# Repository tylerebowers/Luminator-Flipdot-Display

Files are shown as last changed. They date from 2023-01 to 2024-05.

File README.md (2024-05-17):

# Luminator Flipdot Display
 These signs were used in busses to display route information and service status, now they are replaced with led signs (how boring). Flipdots are physical disks "dots" that flip based on an electomagnetic impulse. The only original parts in this project are the flipdot boards themselves (and cables). Though the list is oversimplified, this is what I had to do:   
  * Reverse engineer pinnouts and board workings.
  * Design a PCB driver to drive the display (in Kicad).
  * Software to run on the driver board (C++ on esp32).
  * Software to control the driver board (Python on RPI).
  * Fabricate an enclosure to mount the boards and controllers.  

This project is on hold until I have time to complete the software and make some finishing touches to the housing.

## Pictures (videos in media folder too!)

### Finished (almost) display
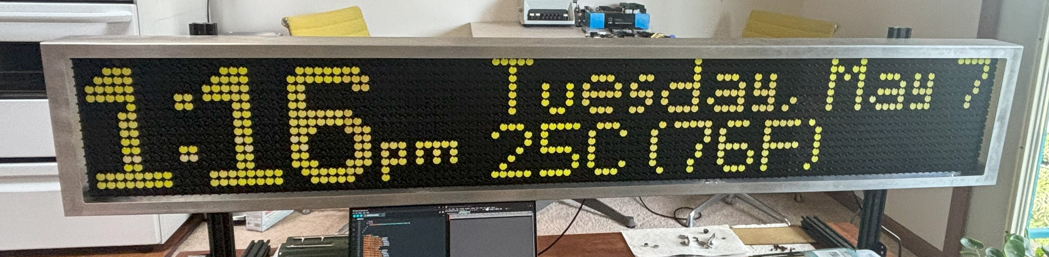
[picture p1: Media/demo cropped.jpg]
Picture of display


### Board
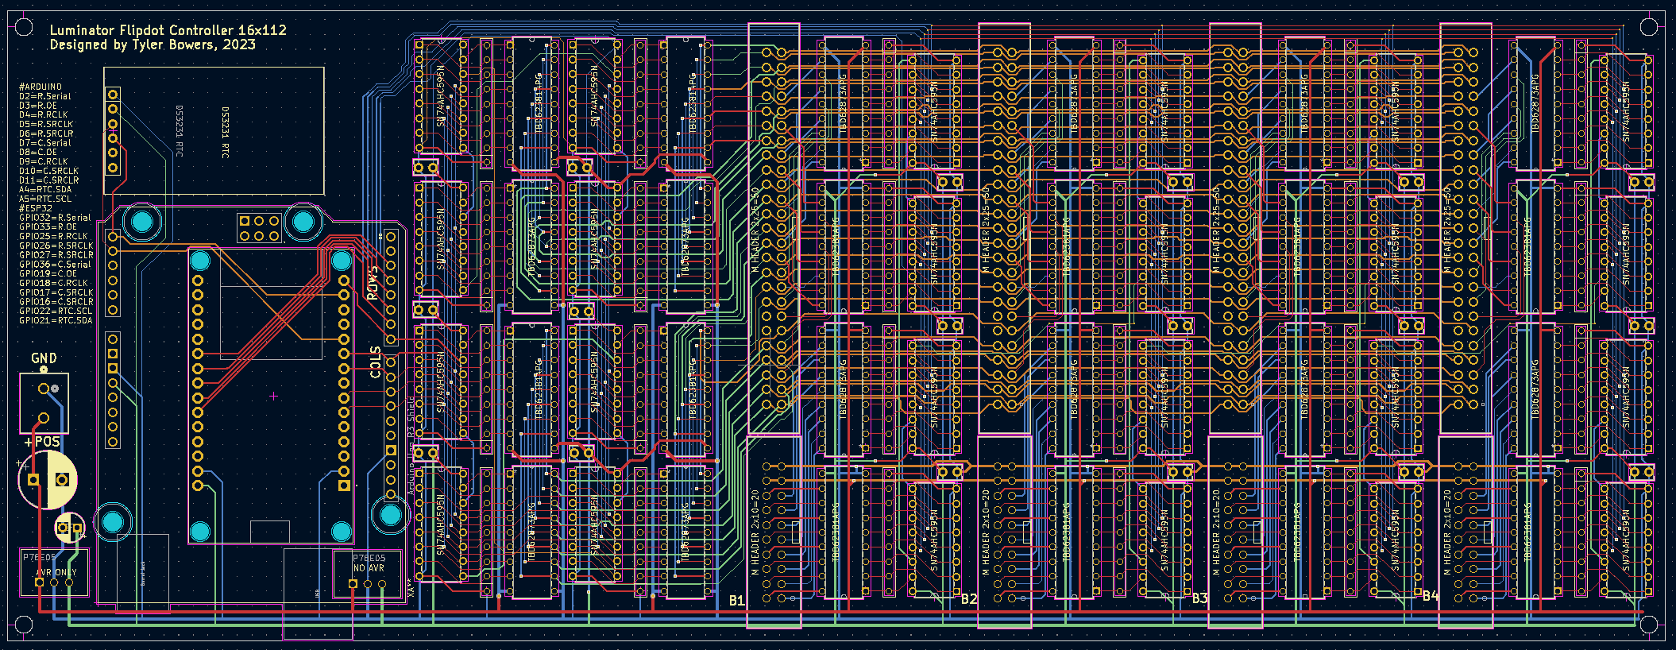
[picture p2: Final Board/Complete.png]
Picture of board


### Populated Board
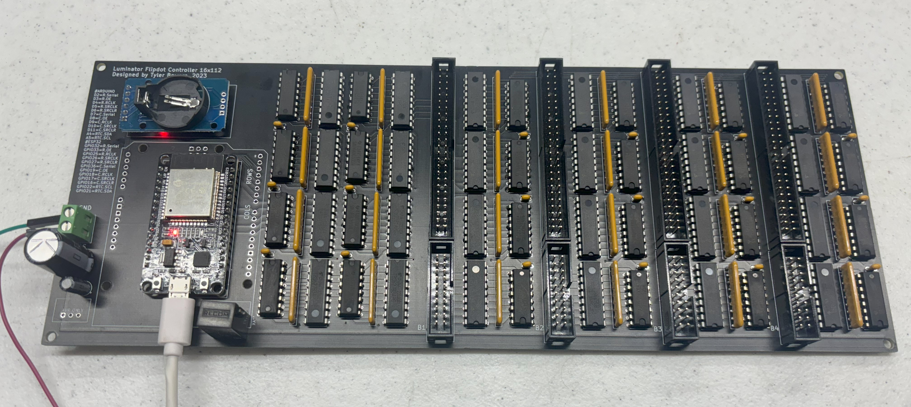
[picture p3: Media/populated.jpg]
Picture of all dots


### Pinnouts
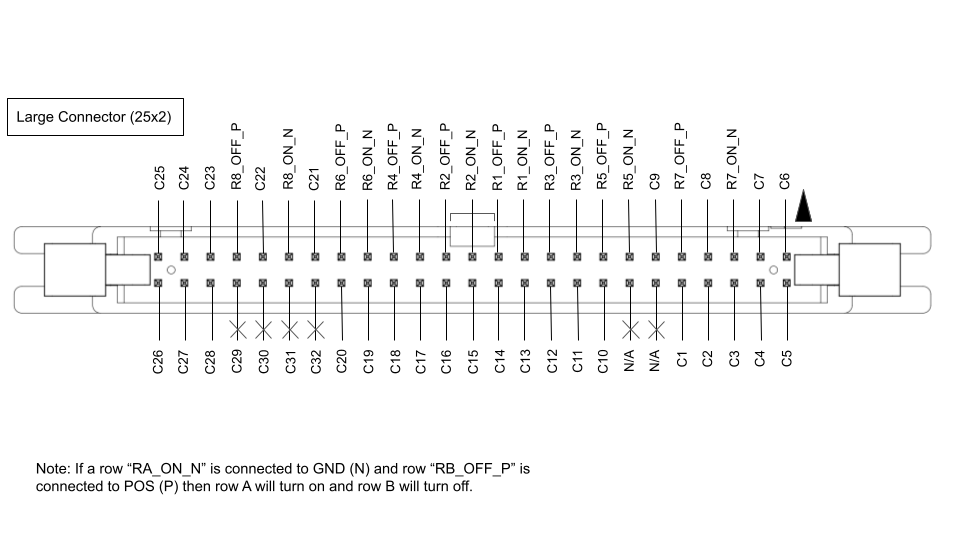
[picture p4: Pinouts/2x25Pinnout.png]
Pinnout 1

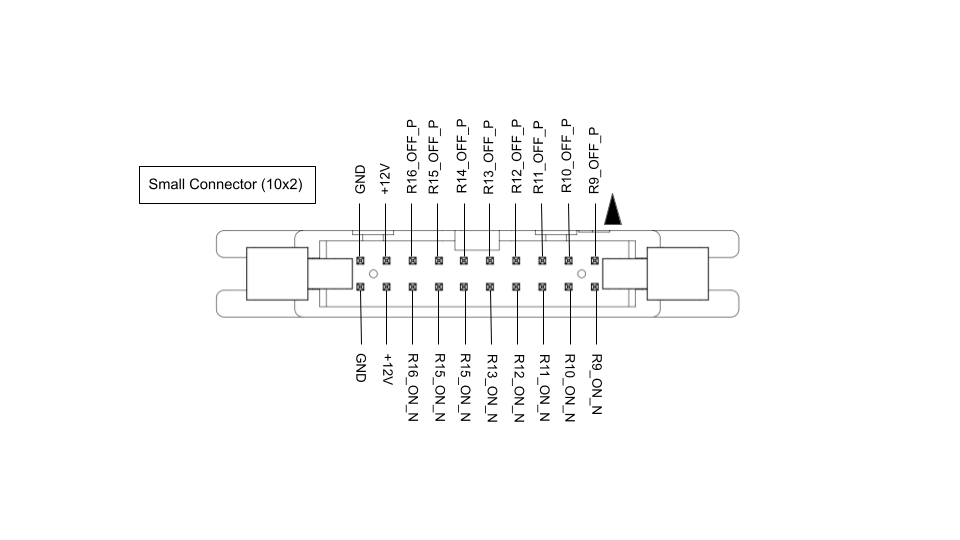
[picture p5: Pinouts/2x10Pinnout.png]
Pinnout 2


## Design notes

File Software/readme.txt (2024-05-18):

The esp32 is on the driver board and it controls the registers and outputs it was originally intended to do the job that the pi now does.
The rpi (zero 2 W) connects over serial (micro-b to micro-b) and runs the software that controls the esp32/driver board. The rpi is better for storing graphics libraries, running webservers, and python is easier to work with so no reflashing everytime a change is made.

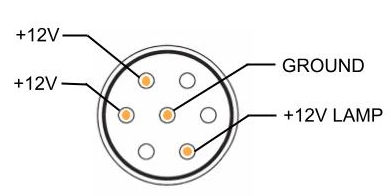
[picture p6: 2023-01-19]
Pinouts/original power connector.jpg

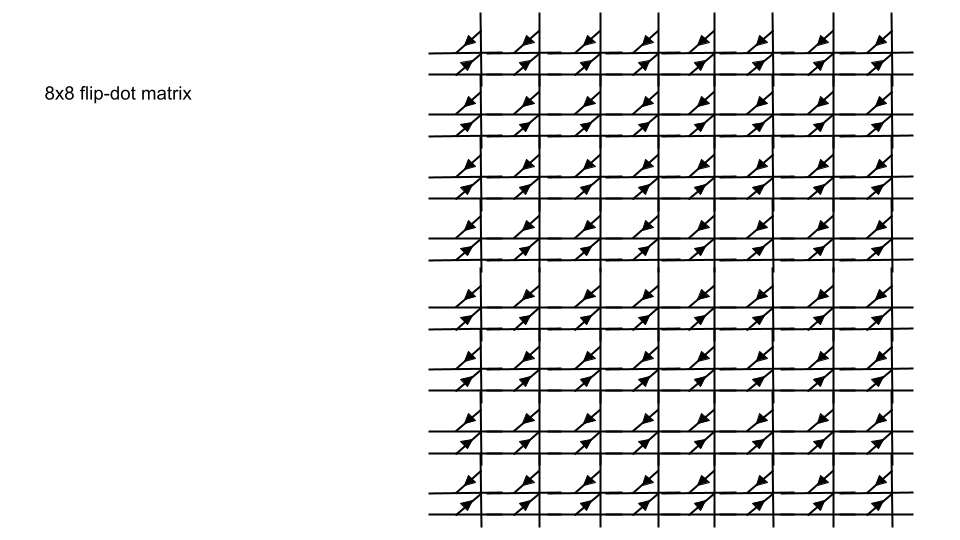
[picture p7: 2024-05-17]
Pinouts/Grid.png

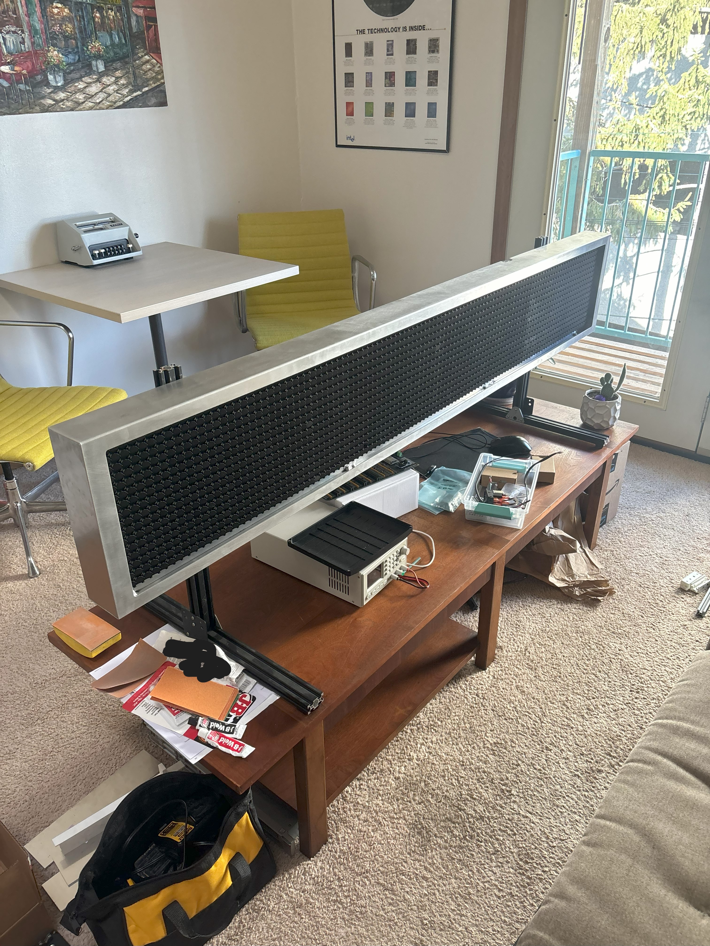
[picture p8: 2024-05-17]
Media/on table.jpg

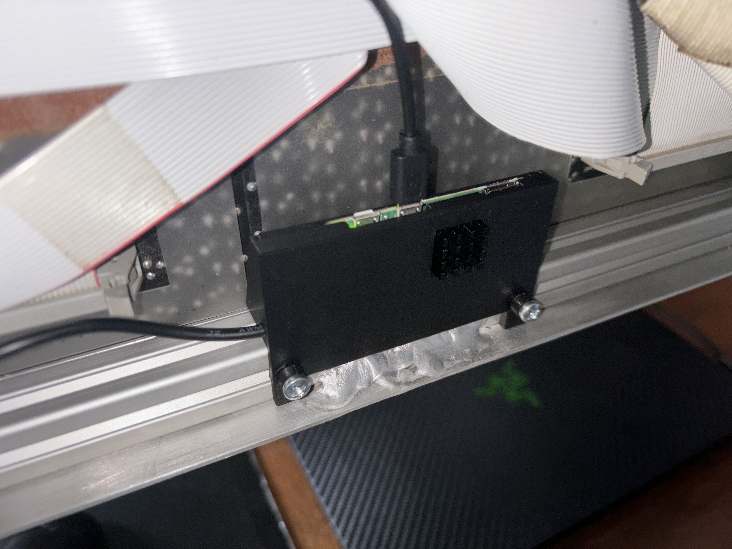
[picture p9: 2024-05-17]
Media/rpi.JPG

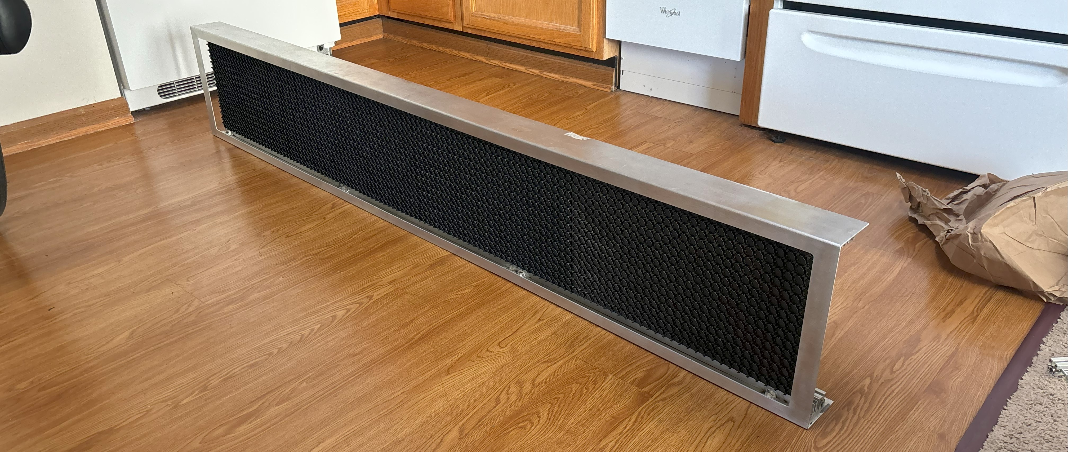
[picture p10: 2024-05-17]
Media/boards in frame.jpg

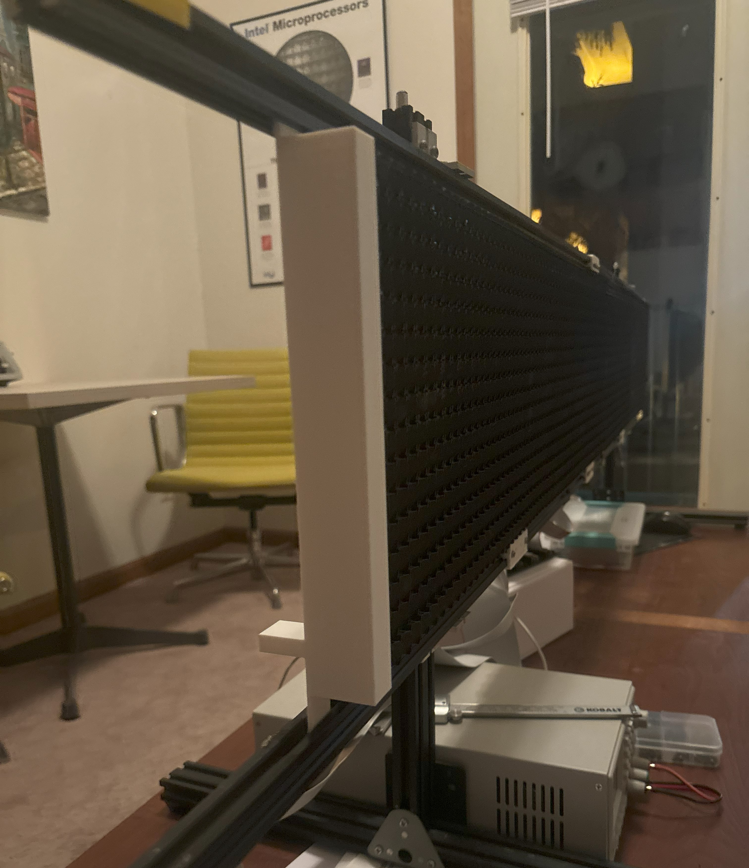
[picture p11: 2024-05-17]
Media/panel profile.jpg

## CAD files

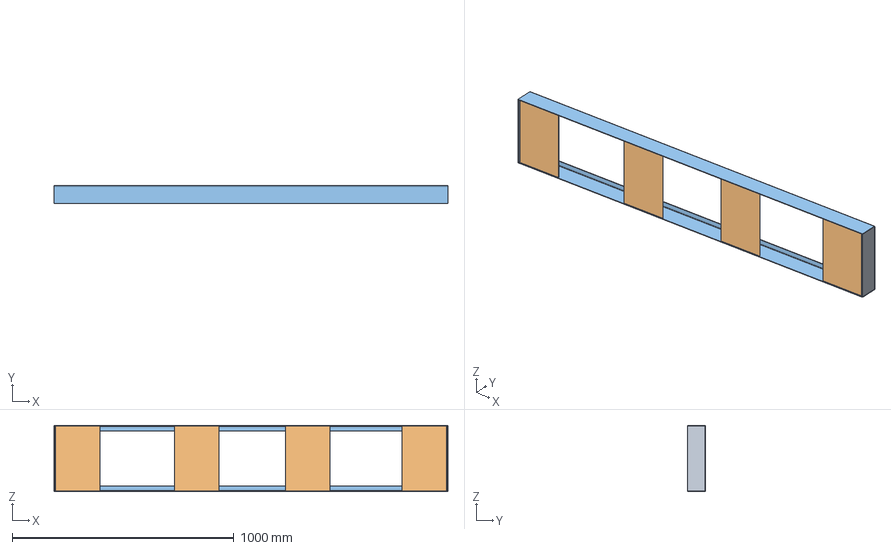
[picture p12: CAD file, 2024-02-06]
Cad/aluminum/Cover FULL.step
1775.8 x 82.3 x 297.8 mm

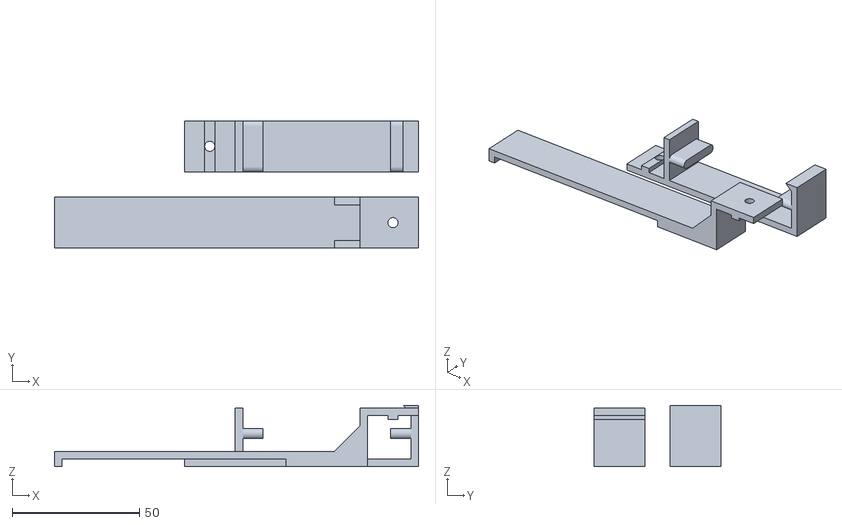
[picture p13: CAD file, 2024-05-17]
Cad/3d print/cable management.stl
143.0 x 50.0 x 24.0

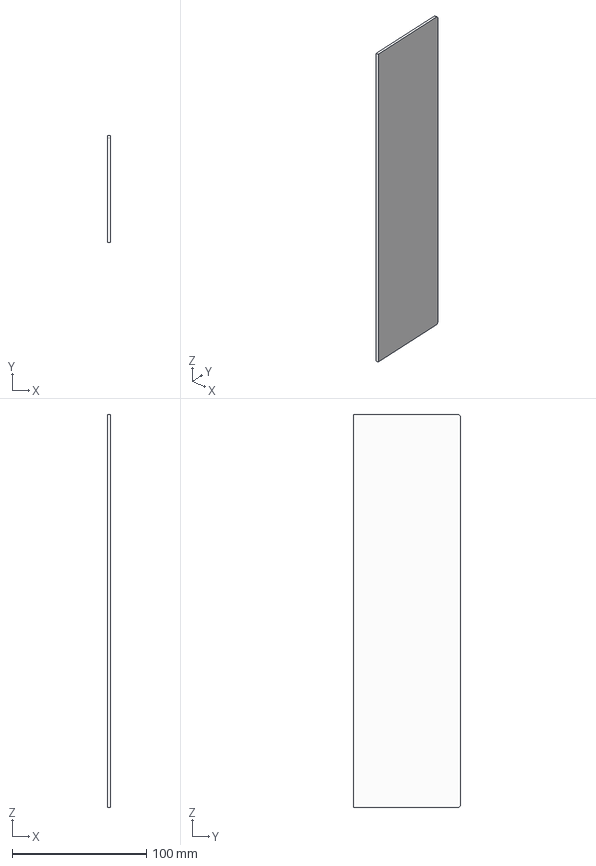
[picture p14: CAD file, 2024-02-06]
Cad/aluminum/2x Side Board.step
2.29 x 79.8 x 292.8 mm

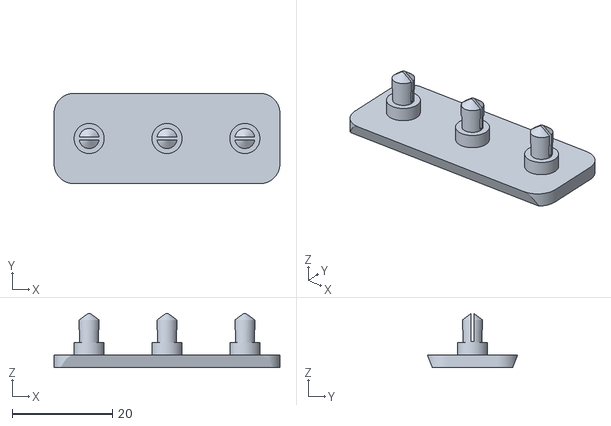
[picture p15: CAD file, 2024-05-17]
Cad/3d print/insulation clip.stl
45.0 x 18.0 x 10.8

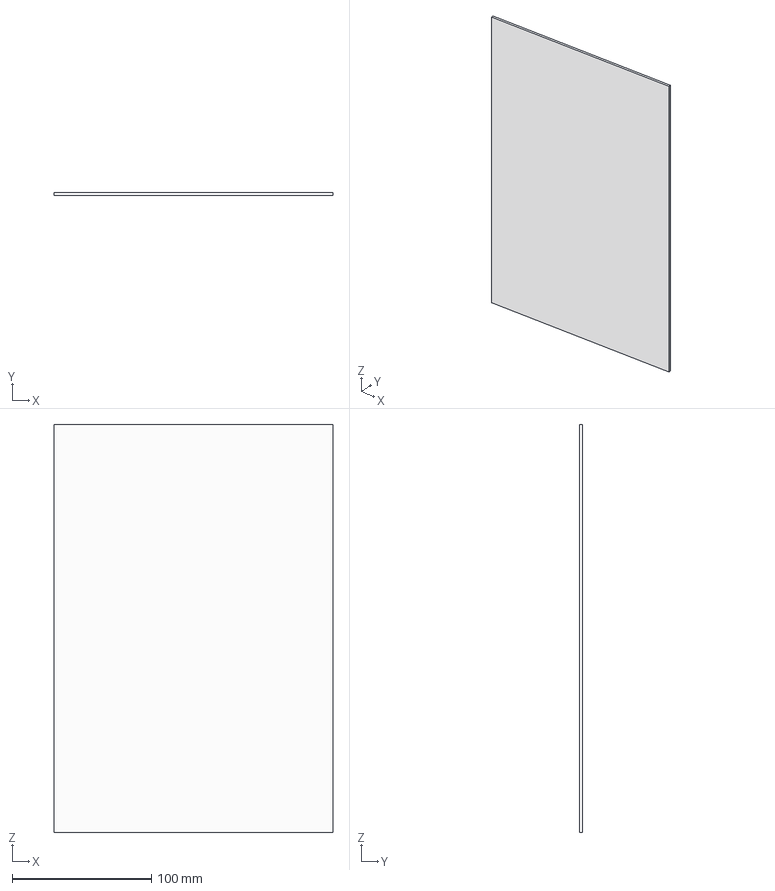
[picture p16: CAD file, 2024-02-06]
Cad/aluminum/4x BackerBoard.step
200.0 x 2.29 x 292.8 mm

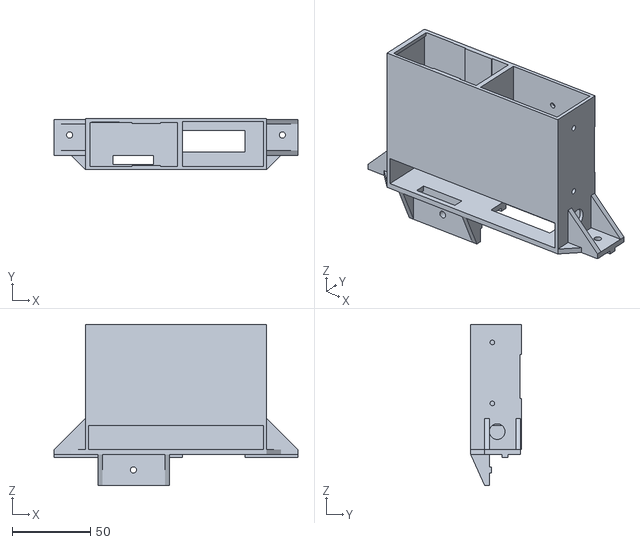
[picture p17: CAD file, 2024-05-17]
Cad/3d print/psu.stl
156.0 x 32.5 x 103.0

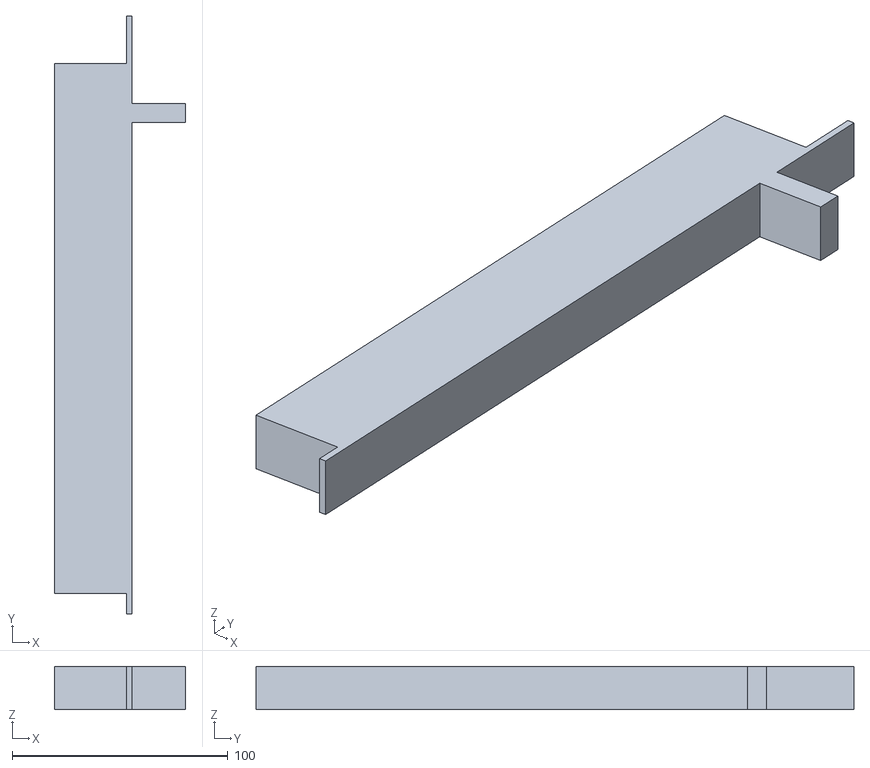
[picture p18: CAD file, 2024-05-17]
Cad/3d print/flipdot bard cross section.stl
61.0 x 277.5 x 20.0

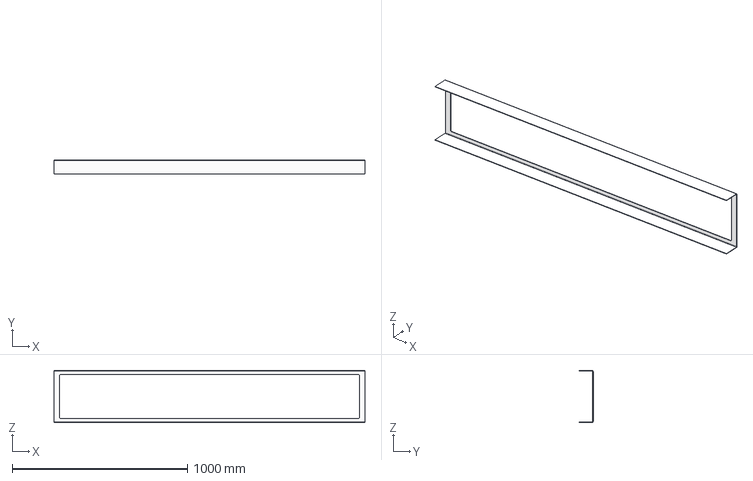
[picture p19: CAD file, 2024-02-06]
Cad/aluminum/Cover.step
1775.8 x 82.3 x 297.8 mm

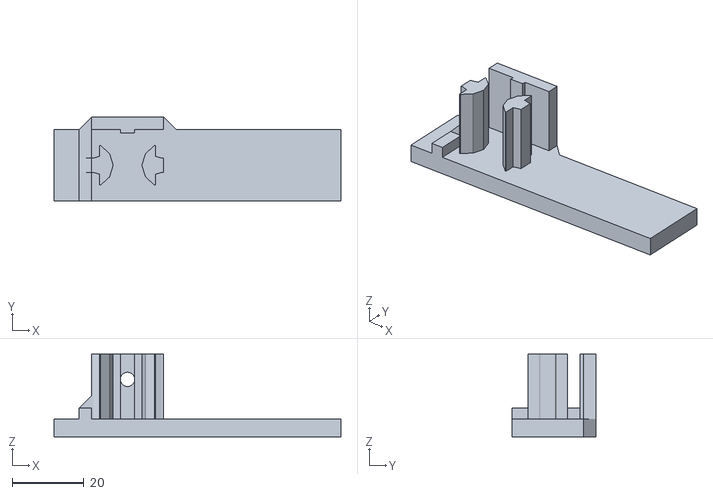
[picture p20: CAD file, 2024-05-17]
Cad/3d print/corner.stl
80.0 x 23.5 x 23.0

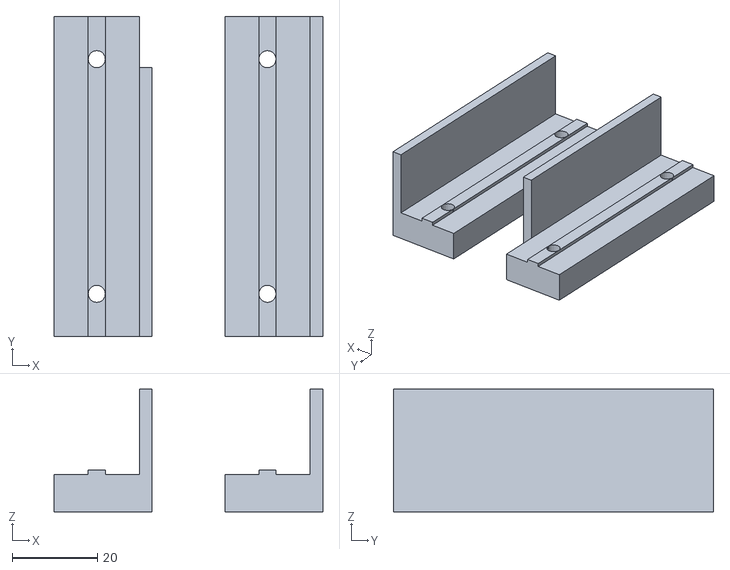
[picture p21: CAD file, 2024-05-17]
Cad/3d print/mounting spacers.stl
63.0 x 75.0 x 28.8

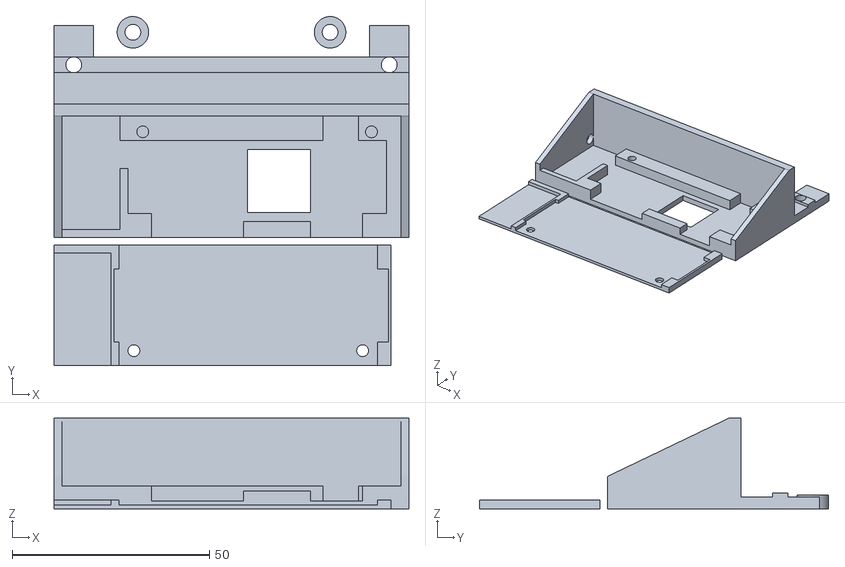
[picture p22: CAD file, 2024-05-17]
Cad/3d print/rpi case.stl
90.0 x 88.5 x 23.0

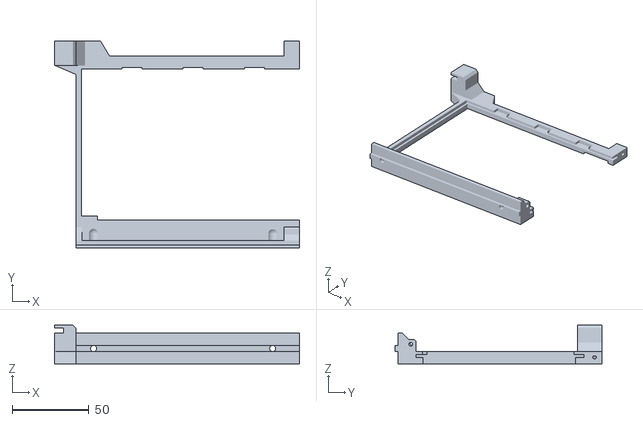
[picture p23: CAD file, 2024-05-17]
Cad/3d print/driver right.stl
160.0 x 135.5 x 25.2

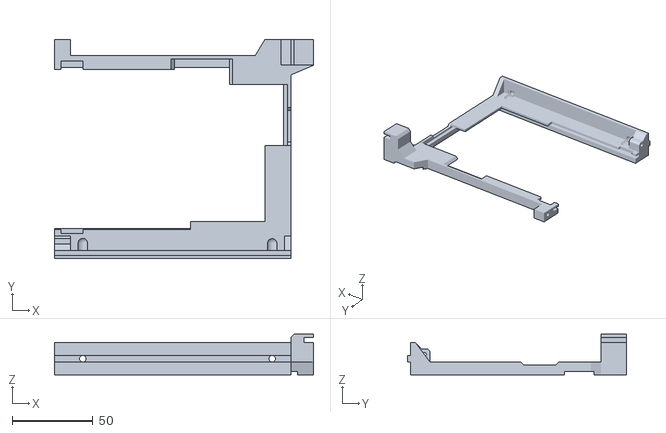
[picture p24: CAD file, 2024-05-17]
Cad/3d print/driver left.stl
160.0 x 135.5 x 25.2

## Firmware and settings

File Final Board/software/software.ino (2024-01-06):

#include <string.h>
#include <WiFi.h>
#include <RTClib.h>
//#include <time.h> 
#include <Wire.h>
#include <LinkedList.h>
//#include "libraries.h"

#define FLASHTIME 200   //in microseconds
#define TIMEZONE "EST5EDT,M3.2.0,M11.1.0"
#define NTP_SERVER "pool.ntp.org"
#define WIFI_SSID ""
#define WIFI_PASSWORD ""

RTC_DS3231 RTC;
DateTime RTCnow;
uint8_t shownMinute = 61;
time_t now;

struct Display{
  uint8_t numRows = 16;
  uint8_t numCols = 112;    // numCols = numBoards * numColsPerBoard
  uint8_t numBoards = 4;
  uint8_t numColsPerBoard = 28;
  uint16_t shown[112];    // datatype is uint16_t because numRows = 16 

  struct Rows{
    uint8_t SER = 32;
    uint8_t OE = 33;
    uint8_t RCLK = 25;
    uint8_t SRCLK = 26;
    uint8_t SRCLR = 27;
    void disable() {
      digitalWrite(OE, HIGH); // disable
    }
    void enable(){
      digitalWrite(OE, LOW); // enable
    }
    void clear(){
      digitalWrite(SRCLR, LOW); // clear
      digitalWrite(SRCLR, HIGH); // clear
    }
    void incrementSR(){
      digitalWrite(SRCLK, HIGH);
      digitalWrite(SRCLK, LOW);
    }
    void incrementR(){
      digitalWrite(RCLK, HIGH);
      digitalWrite(RCLK, LOW);
    }
    void setIdle(){
      digitalWrite(SER, LOW);
    }
  } rows;

  struct Columns{
    uint8_t SER = 23;
    uint8_t OE = 19;
    uint8_t RCLK = 18;
    uint8_t SRCLK = 17;
    uint8_t SRCLR = 16;
    void disable() {
      digitalWrite(OE, HIGH); // disable
    }
    void enable(){
      digitalWrite(OE, LOW); // enable
    }
    void clear(){
      digitalWrite(SRCLR, LOW); // clear
      digitalWrite(SRCLR, HIGH); // clear
    }
    void incrementSR(){
      digitalWrite(SRCLK, HIGH);
      digitalWrite(SRCLK, LOW);
    }
    void incrementR(){
      digitalWrite(RCLK, HIGH);
      digitalWrite(RCLK, LOW);
    }
    void setIdle(){
      digitalWrite(SER, LOW);
    }
  } cols;

  void toggleColumn(short c, bool state){
    cols.disable();
    cols.clear();
    c = c%numColsPerBoard;
    for(int8_t i = 3; i >=0; i--){
      short c_offset = i*8;
      for(int8_t j = 7; j >= 0; j--){ // writes +POS (83) (ON)
        if((j+c_offset == c) && state){
          digitalWrite(cols.SER, HIGH);
        }
        else{
          digitalWrite(cols.SER, LOW);
        }
        cols.incrementSR();
      }
      for(int8_t j = 7; j >= 0; j--){ // writes -GND (81) (OFF)
        if((j+c_offset == c) && !state){
          digitalWrite(cols.SER, HIGH);
        }
        else{
          digitalWrite(cols.SER, LOW);
        }
        cols.incrementSR();
      }
    }
    cols.incrementR();
    cols.setIdle();
  }

  void toggleRow(short r, short c, short state){
    rows.disable();
    rows.clear();
    int8_t board = c/numColsPerBoard;
    for(int8_t b = board; b>=0; b--){
      for(int8_t i = 1; i >=0; i--){
        short r_offset = i*8;
        for(int8_t j = 7; j >= 0; j--){ // writes +POS (83) (OFF)
          if((j+r_offset == r) && !state && (b == board)){
            digitalWrite(rows.SER, HIGH);
          }
          else{
            digitalWrite(rows.SER, LOW);
          }
          rows.incrementSR();
        }
        for(int8_t j = 7; j >= 0; j--){ // writes -GND (81) (ON)
          if((j+r_offset == r) && state && (b == board)){
            digitalWrite(rows.SER, HIGH);
          }
          else{
            digitalWrite(rows.SER, LOW);
          }
          rows.incrementSR();
        }
      }
    }
    rows.incrementR();
    rows.setIdle();
  }

  void flash(short delayTime = FLASHTIME){    // turn on rows and colums for FLASHTIME microseconds 
    rows.enable();
    cols.enable();
    delayMicroseconds(delayTime);
    cols.disable();
    rows.disable();
  }

  void writeDot(uint8_t c, uint8_t r, bool state){ // one dot at a time
    toggleRow(r, c, state);
    toggleColumn(c, state);
    flash();
    shown[c] = (shown[c] & (~(1 << r))) | (state << r);
  }
/*
  void writeCol(uint16_t col, uint8_t x, uint8_t yS, uint8_t yF){ 
    for(uint8_t r = yS; r < min(numRows, yF); r++){ // do each row 
      bool newDot = ((col >> r-yS) & 1);
      if(newDot != ((shown[x] >> r) & 1)){
        writeDot(x, r, newDot);
      }
    }
  }
*/
  void write(uint16_t * array, uint8_t xLim, uint8_t x = 0, uint8_t y = 0, uint8_t yLim = 32){ 
    for(uint8_t c = x; c < numCols && c-x < xLim; c++){ // For each column
      for(uint8_t r = y; r < numRows && r-y < yLim; r++){ // do each row 
        bool newDot = ((array[c-x] >> r-y) & 1);
        if(newDot != ((shown[c] >> r) & 1)){
          writeDot(c, r, newDot);
        }
      }
    }
  }

  void allOff(bool full = true, uint16_t delayTime = 5){
    for(uint8_t j = 0; j<numRows; j++){
      for(uint8_t i = 0; i<numCols; i++){
        if(((shown[j] >> i) & 1) || full){
          writeDot(i,j,0);
          delay(delayTime);
        }
      } 
    }
    for(uint8_t i = 0; i<numCols; i++){
      shown[i] = 0;
    }
  }

  void allOn(bool full = true, uint16_t delayTime = 5){
    for(uint8_t j = 0; j<numRows; j++){
      for(uint8_t i = 0; i<numCols; i++){
        if(((shown[j] >> i) & 0) || full){
          writeDot(i,j,1);
          delay(delayTime);
        }
      } 
    }
    for(uint8_t i = 0; i<numCols; i++){
      shown[i] = 65535;
    }
  }

  void allInvert(uint16_t delayTime = 5){
    for(uint8_t j = 0; j<numRows; j++){
      for(uint8_t i = 0; i<numCols; i++){
        if(((shown[j] >> i) & 1)){
          writeDot(i,j,0);
        } else {
          writeDot(i,j,1);
        }
        delay(delayTime);
      } 
    }
    for(uint8_t i = 0; i<numCols; i++){
      shown[i] = 65535 - shown[i];
    }
  }

} display;


struct UI{


  uint16_t space[1] = {0};

  uint16_t ascii57[95][5] = {	//7r x 5c
    {0,0,0,0,0},      //" "
    {0,0,95,0,0},		  //!
    {0,3,0,3,0},		  //"
    {20,62,20,62,20},	//#
    {70,73,127,73,49},//$
    {6,102,28,51,48},	//%
    {54,73,81,38,88},	//&
    {0,0,3,0,0},		  //'
    {0,62,65,0,0},		//(
    {0,0,65,62,0},		//)
    {0,5,2,5,0},		  //*
    {0,8,28,8,0},	  	//+
    {0,64,32,0,0},		//,
    {0,8,8,8,0},		  //-
    {0,0,64,0,0},		  //.
    {0,96,28,3,0},		///
    {62,65,65,65,62},	//0
    {0,66,127,64,0},	//1
    {66,97,81,73,70},	//2
    {73,73,73,73,54},	//3
    {15,8,8,127,8},		//4
    {79,73,73,73,49},	//5
    {62,73,73,73,48},	//6
    {1,1,97,25,7},		//7
    {54,73,73,73,54},	//8
    {6,73,73,73,62},	//9
    {0,0,36,0,0},		  //:
    {0,64,36,0,0},		//,
    {0,8,20,34,0},		//<
    {0,20,20,20,0},		//=
    {0,34,20,8,0},		//>
    {2,1,81,9,6},		  //?
    {62,93,85,77,62},	//@
    {126,9,9,9,126},	//A
    {127,73,73,73,54},//B
    {62,65,65,65,34},	//C
    {127,65,65,65,62},//D
    {127,73,73,73,73},//E
    {127,9,9,9,9},		//F
    {62,65,65,73,56},	//G
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
  };

  uint16_t largeTime[13][10] = {		                            //14r x 10c
    {4092,8190,14343,12291,12291,12291,12291,14343,8190,4092},	//0
    {0,12300,12302,12303,16383,16383,12288,12288,12288,0},	  	//1
    {0,14342,15367,15875,14083,13187,12739,12543,12414,0},	  	//2
    {0,6150,14343,12291,12483,12483,12483,14535,8190,3900},	  	//3
    {127,255,192,192,192,192,192,16383,16383,192},			        //4
    {12415,12415,12387,12387,12387,12387,12387,14563,8131,3971},//5
    {4094,8191,14563,12387,12387,12387,12387,14563,8135,3974},	//6
    {3,3,3,3,14339,16131,1987,243,63,15},					             	//7
    {3868,8190,14823,12483,12483,12483,12483,14823,8190,3900},	//8
    {60,6270,14567,12483,12483,12483,12483,14567,8190,4092},	  //9
    {0,0,0,0,1560,1560,0,0,0,0},						                		//:
    {0,3584,2560,1536,0,3584,512,3584,512,3584},			        	//am
    {0,15872,2560,3584,0,3584,512,3584,512,3584},		        		//pm
  };

  void writeLine(char * text, bool line = 0){
    uint8_t c = 0;
    uint8_t yLow = line*8;
    uint8_t yHigh = line*8+8;
    for(int16_t i = 0; i<strlen(text) && i<18; i++){
      int8_t charI = text[i]-32;
      if((charI >= 0) && (charI < 95)){
        display.write(ascii57[charI], 5, c, yLow, yHigh);
        c+=5;
        display.write(space, 1, c++, yLow, yHigh);
      }
    }
  }

  void writeTime(uint8_t hour, uint8_t minute, uint8_t c = 0, bool alignLeft = true, bool mt = false){
    uint8_t t[6] = {hour / 10, hour % 10, 10, minute / 10, minute % 10, 11+(hour>=12)};
    int8_t s = 0;
    if(!mt){
      if(hour > 12){t[0]-=1;t[1]-=2;} 
      else if(hour == 0){t[0]=1;t[1]+=2;}
      if(t[0] == 0){s = 1;}
    }
    if(alignLeft){
      c+=10;
      for(int8_t d = 5-mt; d >= s; d--){
        display.write(largeTime[t[d]], 10, display.numCols-c, 1, 15);
        c+=10;
        display.write(space, 1, display.numCols-c++, 0, 16);
      }
    } else {
      for(int8_t d = s; d <= 5-mt; d++){
        display.write(largeTime[t[d]], 10, c, 1, 15);
        c+=10;
        display.write(space, 1, c++, 0, 16);
      }
    }
  }

  void clearLine(bool line = 0, bool largeLetters = 0){
    Serial.println("TODO");
  }

} ui;

/*
struct tm localTime;
void syncRTC(){
  if(WiFi.status() == WL_CONNECTED && getLocalTime(&localTime)){
    RTC.adjust(DateTime(localTime.tm_year+1900, localTime.tm_mon+1, localTime.tm_mday, localTime.tm_hour, localTime.tm_min, localTime.tm_sec));    //update RTC
    Serial.println(&localTime, "Synced RTC: %A, %B %d %Y %H:%M:%S");
  } else if (WiFi.status() != WL_CONNECTED) {
    Serial.println("ERROR: wifi is not connected OR there was a problem getting new time!");
  }
}
*/

void serialPrintDisplay(uint16_t * array = display.shown){
  for(uint8_t r = 0; r<16; r++){
    Serial.print('|');
    for(uint16_t c = 0; c<112; c++){
      if((array[c] >> r) & 1){
        Serial.print('#');
      } else {
        Serial.print(' ');
      }
    }
    Serial.println('|');
  }
}

void userSerialConnection(){
  while(true){
    String userInput  = Serial.readStringUntil('\n');
    if (userInput.length() > 4){
      if(userInput.charAt(0) == '{'){
        uint16_t newDisplay[display.numCols] = {0};
        userInput = userInput.substring(userInput.indexOf('{')+1, userInput.indexOf('}'));
        char *ptr = strtok ((char *)userInput.c_str(), ",");         // get first token
        uint16_t loc = 0;
        while (ptr != NULL && loc < display.numCols){
          Serial.printf("%s,",ptr);
          newDisplay[loc++] = atoi(ptr);
          ptr = strtok(NULL, ",");
        }  
        Serial.println();
        display.write(newDisplay, loc);
      } else if(userInput.charAt(0) == '('){
        uint8_t dot[3] = {0};
        userInput = userInput.substring(userInput.indexOf('(')+1, userInput.indexOf(')'));
        char *ptr = strtok ((char *)userInput.c_str(), ",");         // get first token
        uint16_t loc = 0;
        while (ptr != NULL && loc < 3){
          Serial.printf("%s,",ptr);
          dot[loc++] = atoi(ptr);
          ptr = strtok(NULL, ",");
        } 
        Serial.println();
        if(loc == 3){display.writeDot(dot[0], dot[1], dot[2]);} 
      } else if (userInput == "print") {
        serialPrintDisplay();
      } else if (userInput == "exit") {
        break;  
      } else {
          Serial.println("Recieved incorrectly formatted string.");
      }
    }
  }
}

void setup() {
  Serial.begin(115200);
  pinMode(display.cols.SER, OUTPUT);
  pinMode(display.cols.OE, OUTPUT);
  pinMode(display.cols.RCLK, OUTPUT);
  pinMode(display.cols.SRCLK, OUTPUT);
  pinMode(display.cols.SRCLR, OUTPUT);
  display.cols.disable();
  display.cols.clear();
  pinMode(display.rows.SER, OUTPUT);
  pinMode(display.rows.OE, OUTPUT);
  pinMode(display.rows.RCLK, OUTPUT);
  pinMode(display.rows.SRCLK, OUTPUT);
  pinMode(display.rows.SRCLR, OUTPUT);
  display.rows.disable();
  display.rows.clear();
  display.allOff();

  /*
  //Connect to wifi
  WiFi.begin(WIFI_SSID, WIFI_PASSWORD);
  for(int i = 0; i < 20; i++){
    if(WiFi.status() == WL_CONNECTED){
      Serial.print("WiFi Connection Established! (IP address: ");Serial.print(WiFi.localIP());Serial.println(")");
      break;
    } else {
      Serial.printf("Attempting WiFi connection (%d)\n",i+1);
    }
    delay(1000);
  }
  if(WiFi.status() != WL_CONNECTED){
    Serial.println("WiFi Connection Error!");
  }

  //configure and sync time
  configTzTime(TIMEZONE, NTP_SERVER);
  //syncRTC();
  */
}


void loop() {
  
  ui.writeLine("Hello World");
  serialPrintDisplay();
  Serial.println();
  delay(5000);

  ui.writeLine("ABCDEFGHIJKLMNOPQR", 0);
  ui.writeLine("STUVWXYZ1234567890", 1);
  serialPrintDisplay();
  Serial.println();
  delay(5000);


  display.allOff();
  ui.writeTime(13, 24);
  serialPrintDisplay();
  Serial.println();
  delay(5000);
  
  /*
  struct tm localTime;

  if(!getLocalTime(&localTime)){
    Serial.println("Failed to obtain time");
    return;
  }
  Serial.println(&localTime, "%A, %B %d %Y %H:%M:%S");
  
  ui.writeTime(localTime.tm_hour, localTime.tm_min, 0);

  serialPrintDisplay();

  //syncRTC();
  //RTCnow = RTC.now();
  //Serial.printf("TIME: %d:%d\n",RTCnow.hour(), RTCnow.minute());
  delay(10000);

  while(true){  //wait till next minute
    RTCnow = RTC.now();
    if(RTCnow.minute() != shownMinute){    //update clock
      if(RTCnow.hour() == 12 && RTCnow.minute() == 0){
        syncRTC();
      } 
      RTCnow = RTC.now();
      Serial.printf("TIME: %d:%d\n",RTCnow.hour(), RTCnow.minute());
      writeTime(RTCnow.hour(), RTCnow.minute());
      shownMinute = RTCnow.minute();
      break;
    }
    delay(500);
  }   
  delay(30000);
  */
}

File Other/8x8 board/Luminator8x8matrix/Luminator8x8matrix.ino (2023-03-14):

//this program opperates based on matrix values
//it is memory inefficient the bitwize version uses ~8x less ram.

#define NUMROWS 8
#define NUMCOLS 8
#define FLASHTIME 1   //in milliseconds
#define DEBUG 1


struct shiftRegister{
  short serial;
  short OE;
  short RCLK;
  short SRCLK;
  short SRCLR;
  short rank;
  void disable() {
    digitalWrite(OE, HIGH); // disable
  }
  void enable(){
    digitalWrite(OE, LOW); // enable
  }
  void clear(){
    digitalWrite(SRCLR, LOW); // clear
    digitalWrite(SRCLR, HIGH); // clear
  }
  void incrementSR(){
    digitalWrite(SRCLK, HIGH);
    digitalWrite(SRCLK, LOW);
  }
  void incrementR(){
    digitalWrite(RCLK, HIGH);
    digitalWrite(RCLK, LOW);
  }
  void setIdle(){
    digitalWrite(serial, LOW);
  }
} col, row;

void inverseArray(short * array, short n){
  for(short i = 0; i < n; i++){
    if (array[i]){
      array[i] = 0;
    } else {
      array[i] = 1;
    }
  }
}

void writeColumnArray(short * array, short state){
  col.disable();
  col.clear();
  for(short i = 1; i <= NUMCOLS/8; i++){
    for(short j = 8; j > 0; j--){ // writes +POS (83) (ON)
      if(state == 1 && array[(8*i)-j] == 1){
        digitalWrite(col.serial, HIGH);
      }
      else{
        digitalWrite(col.serial, LOW);
      }
      col.incrementSR();
      col.incrementR();
    }
    for(short k = 8; k > 0; k--){ // writes -GND (81) (OFF)
      if(state == 0 && array[(8*i)-k] == 0){
        digitalWrite(col.serial, HIGH);
      }
      else{
        digitalWrite(col.serial, LOW);
      }
      col.incrementSR();
      col.incrementR();
    }
  }
  col.setIdle();
}

void writeColumnSingle(short index, short state){
  col.disable();
  col.clear();
  for(short i = 1; i <= NUMCOLS/8; i++){
    for(short j = 8; j > 0; j--){ // writes +POS (83) (ON)
      if((state == 1) && ((8*i)-j == index)){
        digitalWrite(col.serial, HIGH);
      }
      else{
        digitalWrite(col.serial, LOW);
      }
      col.incrementSR();
      col.incrementR();
    }
    for(short k = 8; k > 0; k--){ // writes -GND (81) (OFF)
      if((state == 0) && ((8*i)-k == index)){
        digitalWrite(col.serial, HIGH);
      }
      else{
        digitalWrite(col.serial, LOW);
      }
      col.incrementSR();
      col.incrementR();
    }
  }
  col.setIdle();
}

void writeRowArray(short * array, short state){
  row.disable();
  row.clear();
  for(short i = 1; i <= NUMCOLS/8; i++){
    for(short j = 8; j > 0; j--){ // writes +POS (83) (OFF)
      if(state == 0 && array[(8*i)-j] == 0){
        digitalWrite(row.serial, HIGH);
      }
      else{
        digitalWrite(row.serial, LOW);
      }
      row.incrementSR();
      row.incrementR();
    }
    for(short k = 8; k > 0; k--){ // writes -GND (81) (ON)
      if(state == 1 && array[(8*i)-k] == 1){
        digitalWrite(row.serial, HIGH);
      }
      else{
        digitalWrite(row.serial, LOW);
      }
      row.incrementSR();
      row.incrementR();
    }
  }
  row.setIdle();
}

void writeRowSingle(short index, short state){
  row.disable();
  row.clear();
  for(short i = 1; i <= NUMCOLS/8; i++){
    for(short j = 8; j > 0; j--){ // writes +POS (83) (OFF)
      if(state == 0 && (8*i)-j == index){
        digitalWrite(row.serial, HIGH);
      }
      else{
        digitalWrite(row.serial, LOW);
      }
      row.incrementSR();
      row.incrementR();
    }
    for(short k = 8; k > 0; k--){ // writes -GND (81) (ON)
      if(state == 1 && (8*i)-k == index){
        digitalWrite(row.serial, HIGH);
      }
      else{
        digitalWrite(row.serial, LOW);
      }
      row.incrementSR();
      row.incrementR();
    }
  }
  row.setIdle();
}

void flashDisplay(){
  row.enable();
  col.enable();
  delay(FLASHTIME);
  col.disable();
  row.disable();
}

void flashDisplayLong(){
  row.enable();
  col.enable();
  delay(200);
  col.disable();
  row.disable();
}

void writeDisplay(short array[NUMROWS][NUMCOLS]){
  short rowsToWrite[NUMROWS] = {0};
  for(short i = 0; i < NUMCOLS; i++){
    writeRowArray(array[i], 1);
    writeColumnSingle(i, 1);
    flashDisplay(); 
    delay(2*FLASHTIME);   
    writeRowArray(array[i], 0);
    writeColumnSingle(i, 0);
    flashDisplayLong();
    delay(2*FLASHTIME);  
  }
}

void setup() {
  Serial.begin(9600);
  col.serial = 2;
  col.RCLK = 3;
  col.SRCLK = 4;
  col.OE = 5;
  col.SRCLR = 6;
  col.rank = NUMCOLS;
  pinMode(col.serial, OUTPUT);
  pinMode(col.OE, OUTPUT);
  pinMode(col.RCLK, OUTPUT);
  pinMode(col.SRCLK, OUTPUT);
  pinMode(col.SRCLR, OUTPUT);
  col.disable();
  col.clear();
  row.serial = 7;
  row.RCLK = 8;
  row.SRCLK = 9;
  row.OE = 10;
  row.SRCLR = 11;
  row.rank = NUMROWS;
  pinMode(row.serial, OUTPUT);
  pinMode(row.OE, OUTPUT);
  pinMode(row.RCLK, OUTPUT);
  pinMode(row.SRCLK, OUTPUT);
  pinMode(row.SRCLR, OUTPUT);
  row.disable();
  row.clear();
}

void loop() {
  /*
  short rowsOFF[8] = {0,0,0,0,1,1,1,1};
  short rowsON[8] = {1,1,1,1,0,0,0,0};
  for(int i = 0; i < 8; i++){
    writeRowArray(rowsON, 1);
    writeColumnSingle(i, 1);
    flashDisplay();
    delay(2000);
    writeRowArray(rowsOFF, 0);
    writeColumnSingle(i, 0);
    flashDisplay();
    delay(500);
  }
  delay(1000);
  */
  
  for(int i = 0; i < 8; i++){
    for(int j = 0; j < 8; j++){
      delay(30);
      writeRowSingle(i, 1);
      writeColumnSingle(j, 1);
      flashDisplay(); 
    }
  }
  for(int i = 0; i < 8; i++){
    for(int j = 0; j < 8; j++){
      delay(30);
      writeRowSingle(i, 0);
      writeColumnSingle(j, 0);
      flashDisplay(); 
    }
  }
  
  /*
  short circle[NUMCOLS][NUMROWS] = {{0,0,0,0,0,0,0,0},{0,0,0,1,1,0,0,0},{0,0,1,0,0,1,0,0},{0,1,0,0,0,0,1,0},{0,1,0,0,0,0,1,0},{0,0,1,0,0,1,0,0},{0,0,0,1,1,0,0,0},{0,0,0,0,0,0,0,0}};
  short blank[NUMCOLS][NUMROWS] = {{0,0,0,0,0,0,0,0},{0,0,0,0,0,0,0,0},{0,0,0,0,0,0,0,0},{0,0,0,0,0,0,0,0},{0,0,0,0,0,0,0,0},{0,0,0,0,0,0,0,0},{0,0,0,0,0,0,0,0},{0,0,0,0,0,0,0,0}};
  short full[NUMCOLS][NUMROWS] = {{1,1,1,1,1,1,1,1},{1,1,1,1,1,1,1,1},{1,1,1,1,1,1,1,1},{1,1,1,1,1,1,1,1},{1,1,1,1,1,1,1,1},{1,1,1,1,1,1,1,1},{1,1,1,1,1,1,1,1},{1,1,1,1,1,1,1,1}};
  //delay(1000);
  writeDisplay(blank);
  delay(3000);
  writeDisplay(circle);
  delay(3000);
  writeDisplay(full);
  delay(3000);
  */
}

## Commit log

2024-05-17 Update for public release
    [2x Side Board.step, 4x BackerBoard.step, Cover FULL.step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]
2024-05-17 public release update
    [2x Side Board.step, 4x BackerBoard.step, Cover FULL.step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]
